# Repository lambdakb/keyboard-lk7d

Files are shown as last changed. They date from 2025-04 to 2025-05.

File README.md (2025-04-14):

# LK7D 7 Keys Macropad






The LambdaKB LK7D is a simple 7 keys hotswap macropad with per-key RGB LEDs and an OLED display. The goal was to create a simple macropad based on the XIAO RP2040 microcontroller that had all the bells and whispers of a modern keyboard.

This was created as an experiment to learn more about designing PCBs and to have a simple and cheap way to test new features (such as integrating OLED displays and RGB LEDs in QMK / Vial).

## Layout

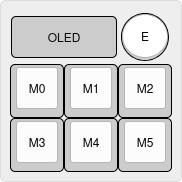
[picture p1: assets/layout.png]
Layout


[Keyboard Layout Editor](https://www.keyboard-layout-editor.com/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)

## PCB

| Front | Back |
| :---: | :---: |
| [PCB Front][PCB Front PNG] | [PCB Back][PCB Back PNG] |

[PCB Front]: output/pcb/img/lk7d-pcb-top.svg
[PCB Front PNG]: output/pcb/img/lk7d-pcb-top.png
[PCB Back]: output/pcb/img/lk7d-pcb-bottom.svg
[PCB Back PNG]: output/pcb/img/lk7d-pcb-bottom.png

The PCB has been designed in [KiCad EDA 9.0](https://www.kicad.org/) using the [`kicad-lkbd`](https://github.com/lambdakb/kicad-lkbd) libraries.

You can preview the project files using [KiCanvas](https://kicanvas.org/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) directly in your browser and download the latest fabrication files for JLCPCB from the [latest release](https://github.com/lambdakb/trackball-lk7d/releases/latest/).

The exported schematic is also available under [`output/schematics`](output/schematics/).

### PCB Order

| Parameters | Value |
| --- | --- |
| Base Material | FR4 |
| Layers | 2 |
| Dimensions | 57.15 × 57.15 mm |
| PCB Thickness | 1.6 mm |
| PCB Color [^pcb-color] | Black |
| Silkscreen | White |
| Surface Finish [^surface-finish] | Lead Free HASL or ENIG |
| Copper Weight | 1 oz |
| Via Covering | Tented |
| Min Via Hole Size | 0.3 mm |
| Board Outline Tolerance | ± 0.2 mm |

[^pcb-color]: You can select any PCB color you want but some manufacturers such as JLCPCB may charge you more for uncommon combos (such as Blue PCB + ENIG Surface Finish).
[^surface-finish]: The "HASL (with lead)" option is extremely discouraged due to the risk of lead poisoning. We strongly recommend paying the premium for the "Lead Free HASL" option.

### BOM

| Part | Ref. | Quantity | Optional | Remarks |
| --- | --- | :---: | :---: | --- |
| PCB | [LK7D PCB](./pcb/) | 1 | ❌ | The PCB itself. |
| XIAO RP2040 Controller | [SeeedStudio XIAO RP2040] | 1 | ❌ | Main controller for QMK/Vial. |
| 1N418 Diodes | [1N4148W T4 SOD-323] | 7 | ❌ | Switch matrix diodes. One MUST be installed under the encoder. |
| Kailh Hot-Swap Sockets | [CPG151101S11-16] | 6 | ❌ | MX style hot-swap sockets. |
| Key Switches | Any [Cherry MX] Compatible Switch | 6 | ❌ | MX style switches. |
| Rotary Encoder | Any [EC11] / [EC12] style 5-pin Encoder | 1 | ❌ | Can be installed either in top left or top right of the PCB. Only one per PCB is supported. |
| 100nF Capacitor | [1206 SMD Ceramic Capacitor] | 2-3 | ✅ | Both C1 and C2 should be installed if populated, used for noise filtering of encoder readings. C3 is only required if a Logic Level Shifter is installed. |
| 0.91" OLED Display | [SSD1306 0.91" 128X32 OLED I²C Display Module] | 1 | ✅ | Optional, occupies the place of the non-populated encoder and sits on top of the XIAO MCU. |
| RGB LEDs | [SK6812MINI-E] | 6 | ✅ | Optional, RGB LEDs can be installed under each key switch. |
| 5V Logic Level Converter | [SN74AHCT1G125DBVR] or [SN74LV1T125DBVR] (SOT-23-5) | 1 | ✅ | Optional, required if your RGB LEDs are not 3.3V logic tolerant. You MUST cut the JP1 jumper if populated. |

[SeeedStudio XIAO RP2040]: https://www.seeedstudio.com/XIAO-RP2040-v1-0-p-5026.html
[1N4148W T4 SOD-323]: https://www.aliexpress.com/item/1005006127619725.html
[CPG151101S11-16]: https://www.aliexpress.com/item/1005007052649640.html
[Cherry MX]: https://www.aliexpress.com/item/1005006255961111.html
[EC11]: https://www.aliexpress.com/item/32382989585.html
[EC12]: https://www.aliexpress.com/item/1005005196870256.html
[1206 SMD ceramic capacitor]: https://www.aliexpress.com/item/32966490820.html
[SSD1306 0.91" 128X32 OLED I²C Display Module]: https://www.aliexpress.com/item/32777216785.html
[SK6812MINI-E]: https://www.aliexpress.com/item/1005006473087141.html
[SN74AHCT1G125DBVR]: https://www.aliexpress.com/item/1005005379322968.html
[SN74LV1T125DBVR]: https://www.digikey.com/en/products/detail/texas-instruments/SN74LV1T125DBVR/4555571

## Case

Coming soon.

## Firmware

The pre-build firmware available in this repository are compiled using [Vial](https://get.vial.today/) (a fork of [QMK](https://qmk.fm) allowing customization via a GUI).

As per the original license of both Vial and QMK, the firmware itself is licensed under the GPLv3 license and its source code is available at [`vial-qmk/keyboards/lambdakb/lk7d`](https://github.com/lambdakb/vial-qmk/tree/lambdakb/keyboards/lambdakb/lk7d).

### Default Vial Keymap

| Layer 0 | Layer 1 | Layer 2 | Layer 3 |
| --- | --- | --- | --- |
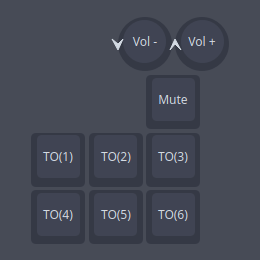
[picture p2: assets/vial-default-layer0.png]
Keymap Layer 0
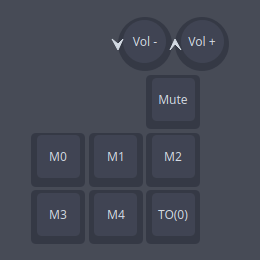
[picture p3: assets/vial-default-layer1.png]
Keymap Layer 1
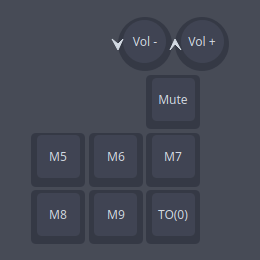
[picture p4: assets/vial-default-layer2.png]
Keymap Layer 2
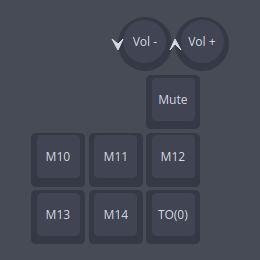
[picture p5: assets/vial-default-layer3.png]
Keymap Layer 3
|  |  |  |  |

[Keymap Layer 0]: assets/vial-default-layer0.png
[Keymap Layer 1]: assets/vial-default-layer1.png
[Keymap Layer 2]: assets/vial-default-layer2.png
[Keymap Layer 3]: assets/vial-default-layer3.png

Layer 4, 5 and 6 contains similar layouts with macro keys going from M15 to M29.

### Vial Layout Options

| Encoder Position: Left | Encoder Position: Right |
| --- | --- |
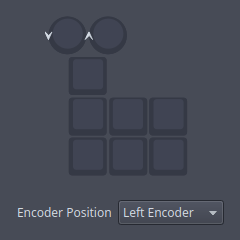
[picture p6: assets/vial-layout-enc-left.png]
Layout Encoder Left
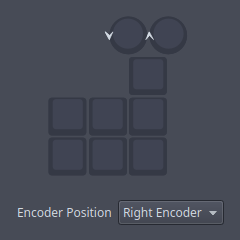
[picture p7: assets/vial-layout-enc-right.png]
Layout Right Encoder
|  |  |

[Layout Encoder Left]: assets/vial-layout-enc-left.png
[Layout Right Encoder]: assets/vial-layout-enc-right.png

## License

This design is licensed under the [CERN Open Hardware Licence Version 2 – Strongly Reciprocal (CERN-OHL-S-2.0)](https://opensource.org/license/cern-ohl-s).

You are free to use, modify, and distribute this design for any purpose, provided that:

- **Attribution**: Appropriate credit is given, a link to the license is provided, and any modifications are clearly indicated.
- **Reciprocity**: Any derivative works must be released under the same license.

If you are a retailer or business interested in producing or selling this design or related products, I’d love to discuss it! Please feel free to reach out so we can explore potential arrangements.

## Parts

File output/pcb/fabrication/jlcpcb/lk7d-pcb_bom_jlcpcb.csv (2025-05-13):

Comment | Designator | Footprint Type | Footprint | LCSC | JLC | QTY
100nF | C1,C2 | SMD | Capacitor_SMD_1206_inSilk | C24497 | 1206 | 2
1N4148 | D1,D2,D3,D4,D5,D6,D7,D8 | SMD | Diode_SMD_SOD-123_inSilk | C81598 | SOD-323 | 8
SK6812MINI-E | LED1,LED2,LED3,LED4,LED5,LED6 | SMD | LED_SK6812MINI-E | C5149201 | SMD | 6
SW_Push | SW3,SW4,SW5,SW6,SW7,SW8 | SMD | SW_MX_HotSwap_sqSilk | C2803348 | SMD | 6
XIAO-RP2040 | U1 | THT | MCU_XIAO_RP2040 | C9900177322 | SMD-14P | 1

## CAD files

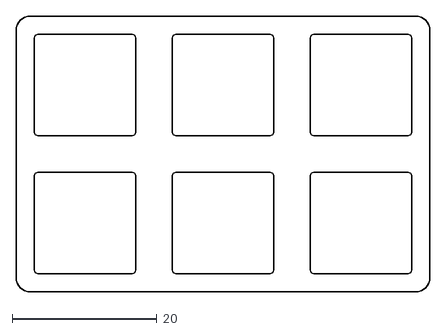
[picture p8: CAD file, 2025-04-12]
output/plate/dxf/lk7d-plate.dxf
57.1 x 38.1

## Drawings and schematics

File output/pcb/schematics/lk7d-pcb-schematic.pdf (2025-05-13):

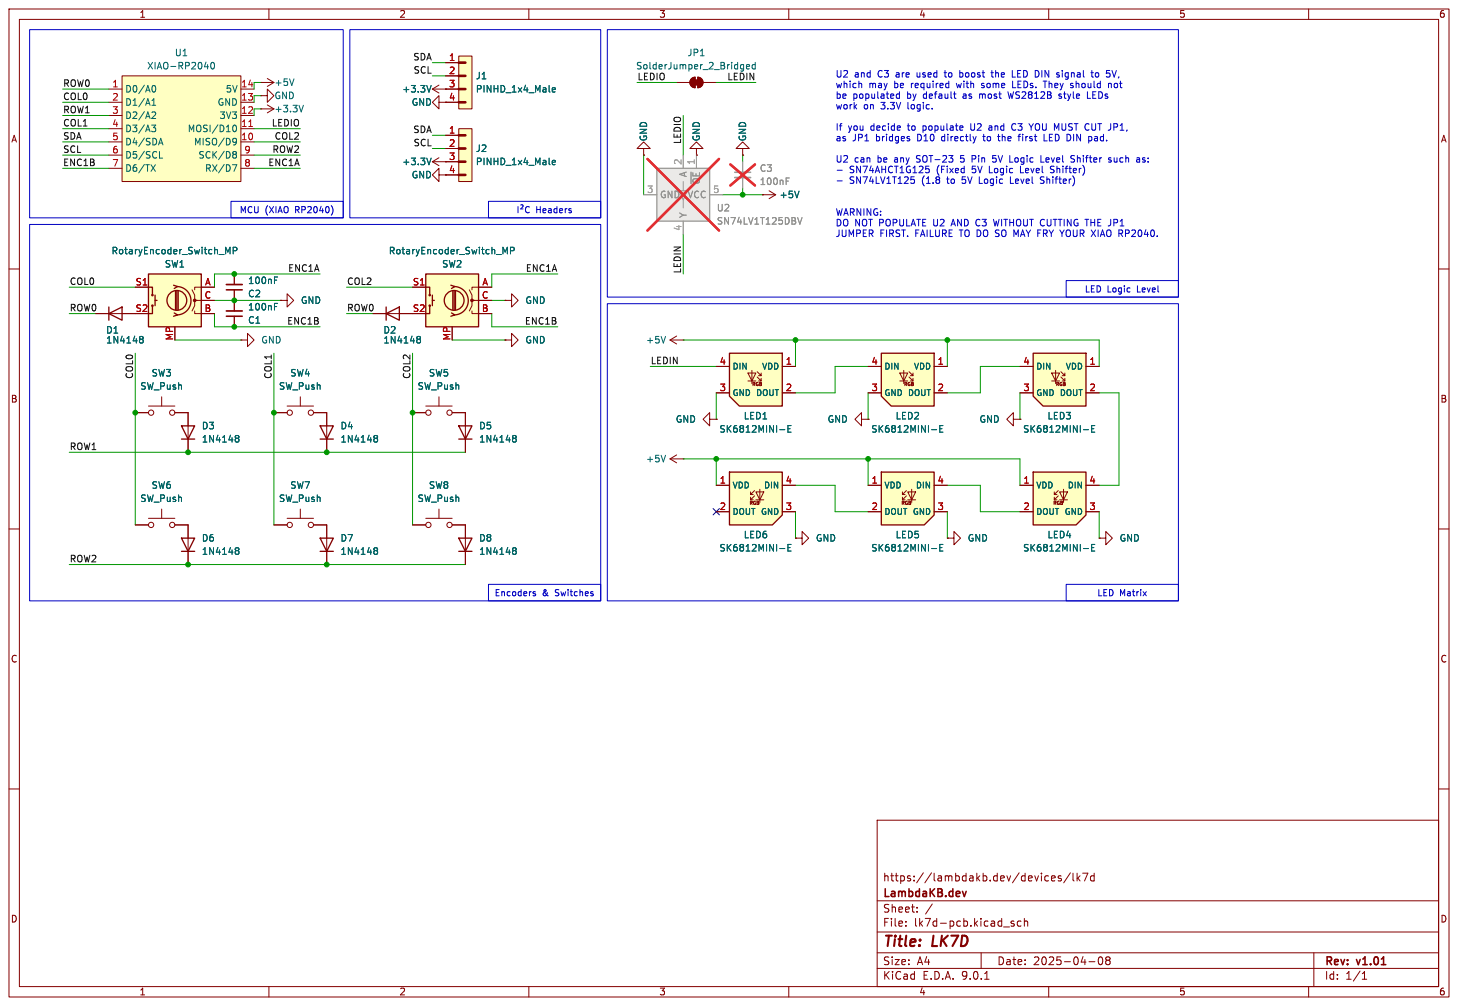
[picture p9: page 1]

þÿI²CHeaders GND GND

- SN74LV1T125 (1.8 to 5V Logic Level Shifter) WARNING: DO NOT POPULATE U2 AND C3 WITHOUT CUTTING THE JP1

RGBVDD 1 DOUT 2 DIN 4 GND 3

VDD 1 DOUT 2 DIN 4 GND 3

https://lambdakb.dev/devices/lk7d
File: lk7d-pcb.kicad_sch Sheet: / LambdaKB.dev

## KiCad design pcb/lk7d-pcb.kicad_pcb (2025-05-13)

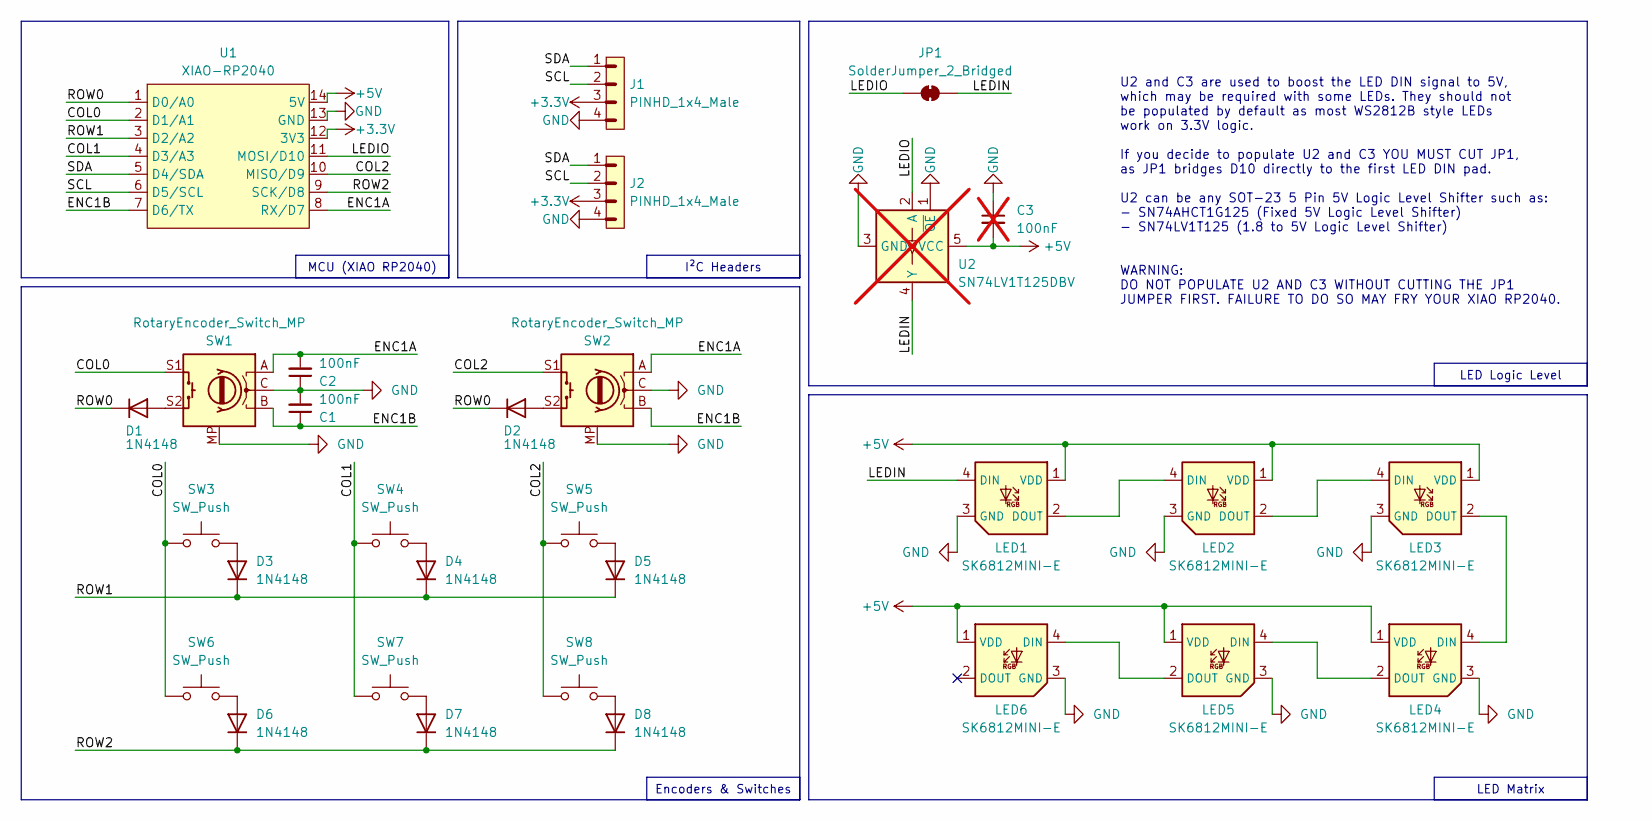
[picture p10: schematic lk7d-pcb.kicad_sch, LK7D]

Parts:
C1, C2: 100nF; Capacitor_SMD_1206_inSilk; LCSC C24497
C3: 100nF; Capacitor_SMD_1206_inSilk; JLC 1206; not fitted
D1, D2, D3, D4, D5, D6, D7, D8: 1N4148; Diode_SMD_SOD-123_inSilk; LCSC C81598
J1, J2: PINHD_1x4_Male; PinHeader_1x04_P2.54mm_Vertical
JP1: SolderJumper_2_Bridged; SolderJumper-2_P1.3mm_Bridged_RoundedPad1.0x1.5mm
LED1, LED2, LED3, LED4, LED5, LED6: SK6812MINI-E; LED_SK6812MINI-E; JLC SMD
SW1, SW2: RotaryEncoder_Switch_MP; ROT_EC11_THT_sqSilk
SW3, SW4, SW5, SW6, SW7, SW8: SW_Push; SW_MX_HotSwap_sqSilk; JLC SMD
U1: XIAO-RP2040; MCU_XIAO_RP2040; JLC SMD-14P
U2: SN74LV1T125DBV; SOT-23-5; JLC SOT-23-5; not fitted

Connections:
+3.3V: J1.3, J2.3, U1.12 (3V3)
+5V: C3.2, LED1.1 (VDD), LED2.1 (VDD), LED3.1 (VDD), LED4.1 (VDD), LED5.1 (VDD), LED6.1 (VDD), U1.14 (5V), U2.5 (VCC)
/COL0: SW1.S1, SW3.1, SW6.1, U1.2 (D1/A1)
/COL1: SW4.1, SW7.1, U1.4 (D3/A3)
/COL2: SW2.S1, SW5.1, SW8.1, U1.10 (MISO/D9)
/ENC1A: C2.2, SW1.A, SW2.A, U1.8 (RX/D7)
/ENC1B: C1.1, SW1.B, SW2.B, U1.7 (D6/TX)
/LEDIN: JP1.2 (B), LED1.4 (DIN), U2.4 (Y)
/LEDIO: JP1.1 (A), U1.11 (MOSI/D10), U2.2 (A)
/ROW0: D1.1 (K), D2.1 (K), U1.1 (D0/A0)
/ROW1: D3.1 (K), D4.1 (K), D5.1 (K), U1.3 (D2/A2)
/ROW2: D6.1 (K), D7.1 (K), D8.1 (K), U1.9 (SCK/D8)
/SCL: J1.2, J2.2, U1.6 (D5/SCL)
/SDA: J1.1, J2.1, U1.5 (D4/SDA)
GND: C1.2, C2.1, C3.1, J1.4, J2.4, LED1.3 (GND), LED2.3 (GND), LED3.3 (GND), LED4.3 (GND), LED5.3 (GND), LED6.3 (GND), SW1.C, SW1.MP, SW2.C, SW2.MP, U1.13 (GND), U2.1 (~OE), U2.3 (GND)
unnamed: D1.2 (A), SW1.S2
unnamed: D2.2 (A), SW2.S2
unnamed: D3.2 (A), SW3.2
unnamed: D4.2 (A), SW4.2
unnamed: D5.2 (A), SW5.2
unnamed: D6.2 (A), SW6.2
unnamed: D7.2 (A), SW7.2
unnamed: D8.2 (A), SW8.2
unnamed: LED1.2 (DOUT), LED2.4 (DIN)
unnamed: LED2.2 (DOUT), LED3.4 (DIN)
unnamed: LED3.2 (DOUT), LED4.4 (DIN)
unnamed: LED4.2 (DOUT), LED5.4 (DIN)
unnamed: LED5.2 (DOUT), LED6.4 (DIN)

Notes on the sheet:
LED Matrix
U2 and C3 are used to boost the LED DIN signal to 5V, which may be required with some LEDs. They should not be populated by default as most WS2812B style LEDs work on 3.3V logic. If you decide to populate U2 and C3 YOU MUST CUT JP1, as JP1 bridges D10 directly to the first LED DIN pad. U2 can be an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
MCU (XIAO RP2040)
I²C Headers
LED Logic Level
Encoders & Switches

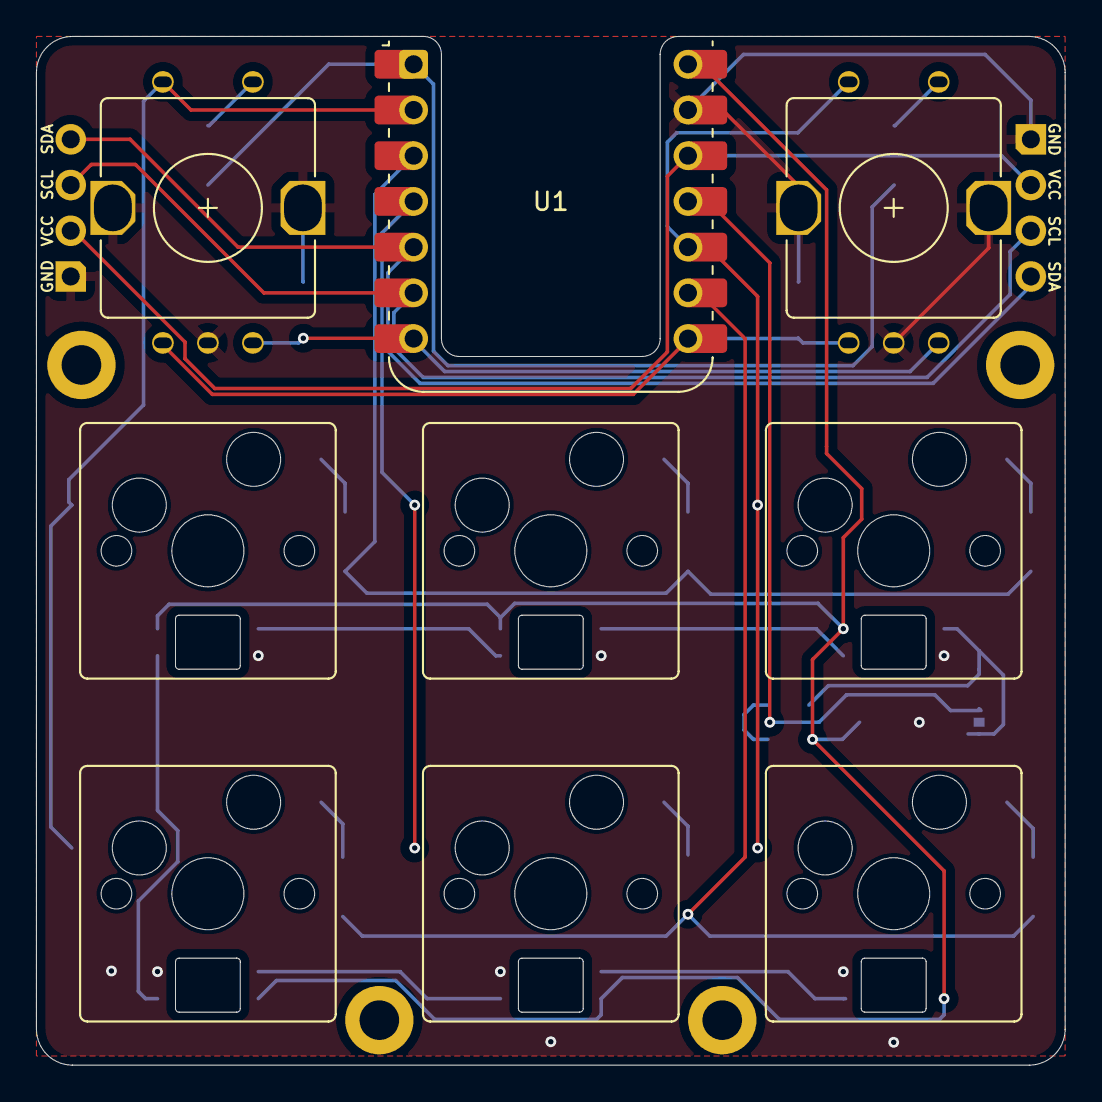
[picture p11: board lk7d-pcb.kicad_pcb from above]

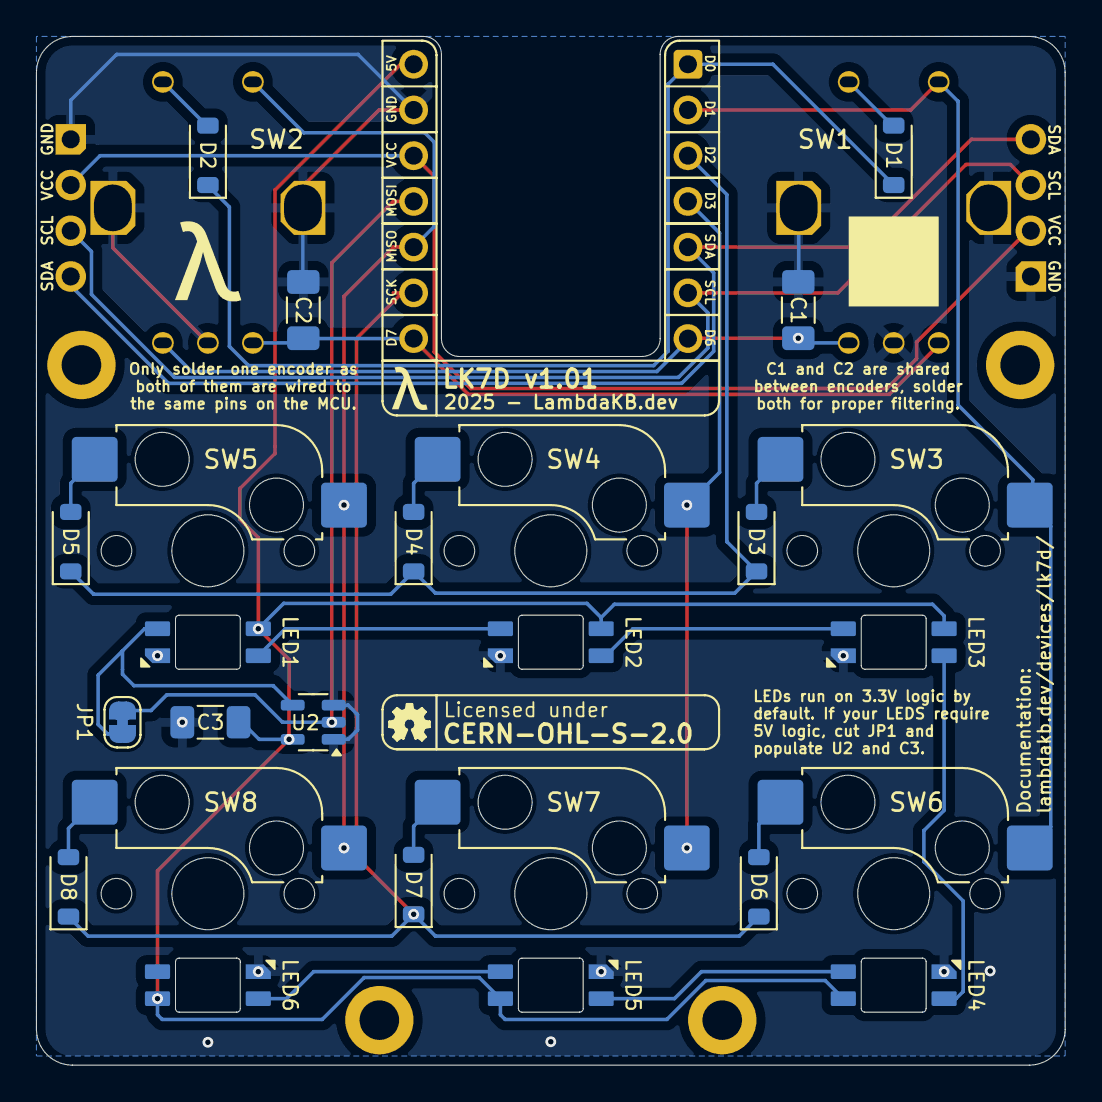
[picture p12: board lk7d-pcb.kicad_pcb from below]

Board: 2 copper layers, 57.2 x 57.2 mm, 35 parts (26 on the bottom side), 28 nets.

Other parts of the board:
H1, H2, H3, H4: MountingHole_2.2mm_M2_ISO14580_Pad
M1: JLCPCB_2DBarcode_5x5mm

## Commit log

2025-03-24 Initial LK7D prototype
    [lk7d-pcb.kicad_pcb, lk7d-pcb.kicad_sch]
2025-03-24 Update silkscreen
    [lk7d-pcb.kicad_pcb]
2025-03-28 Fix Data Matrix Code positioning (#1)
    Fix Data Matrix Code positioning following JLCPCB feedbacks
    [lk7d-pcb-3D.step, lk7d-pcb.kicad_pcb]
2025-03-28 Add BOM to README.md (#2)
2025-04-10 Add Logic Level Converter for per key LEDs (#3)
    [lk7d-pcb-3D.step, lk7d-pcb.kicad_pcb, lk7d-pcb.kicad_sch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]
2025-04-12 Add plate and cleanup PCB (#4)
    [lk7d-pcb-3D.step, lk7d-pcb.kicad_pcb, lk7d-pcb.kicad_sch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]
2025-04-12 Add missing components to BOM (#5)
2025-04-12 Make plate a separate PCB (#6)
    * Make the plate a separate PCB
    * Update PCB 3D models and add layout to README.md
    * Format README.md
    [lk7d-pcb.kicad_pcb, lk7d-pcb_bom_jlcpcb.csv, lk7d-plate.dxf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]
2025-04-12 Fix plate export (#7)
    [lk7d-plate.dxf, lk7d-plate.kicad_pcb]
2025-05-13 Update LKBD libraries (#9)
    [lk7d-pcb.kicad_pcb, lk7d-pcb.kicad_sch, lk7d-pcb_bom_jlcpcb.csv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]

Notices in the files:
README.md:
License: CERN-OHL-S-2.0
